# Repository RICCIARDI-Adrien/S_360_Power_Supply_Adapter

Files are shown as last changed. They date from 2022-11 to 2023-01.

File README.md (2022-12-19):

# S-360-xx power supply adapter

Add 4 10-A 2.5x5.5mm jack outputs and a 240V IEC connector with a switch to S-360-5 and S-360-12 AC/DC power supplies.

Finished casing side view
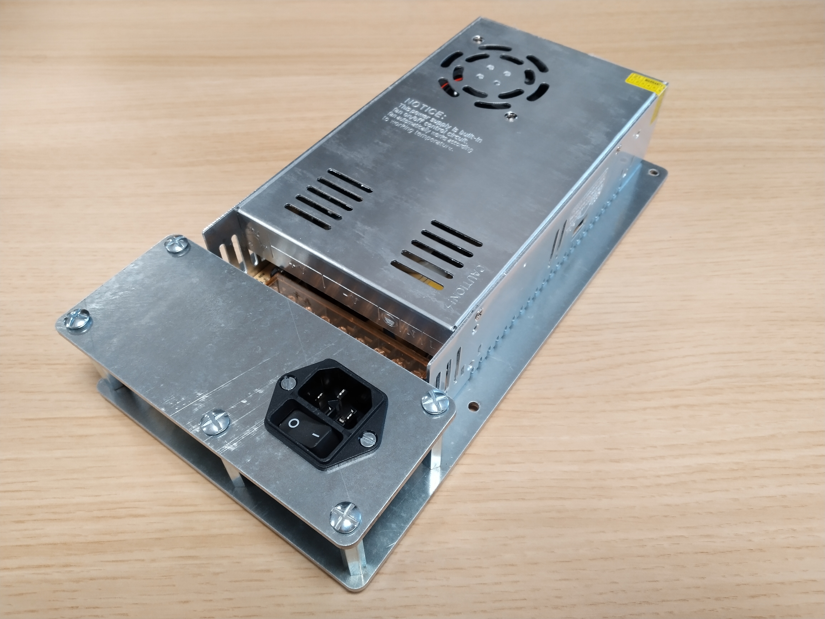
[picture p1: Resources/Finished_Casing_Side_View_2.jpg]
Finished casing side view


## Bill of materials

### Electronic parts

| Description | Reference | Amount |
| --- | --- | --- |
| IEC connector with integrated switch | DC11.0001.007 | 1 |
| 2.5X5.5mm power connector jack | PJ-082BH | 4 |

### Mechanical parts

| Description | Reference | Amount | Description |
| --- | --- | --- | --- |
| 40mm M4 steel hex standoff | 970400471 | 5 | Between upper plate and lower plate |
| 25mm M4 steel screw | - | 4 | Hold PCB |
| 10mm M4 steel screw | - | 14 | Fix upper plate to hex standoffs (5 screws), fix lower plate to hex standoffs (5 screws), fix power supply to lower plate (4 screws) |
| 16mm M3 steel screw | - | 4 | Fix IEC connector to upper plate |
| M4 steel nut | - | 12 | Hold PCB |
| M3 steel nut | - | 2 | Fix IEC connector to upper plate |
| 10mm M4 steel washer | - | 30 | Lock upper plate to hex standoffs (5 washers), lock lower plate to hex standoffs (5 washers), lock power supply to lower plate (4 washers), 4 per PCB screw (16 washers) |
| M3 steel washer | - | 2 | Lock IEC connector to upper plate |

## Documentation

The power supply drawing, found [here](https://fr.aliexpress.com/item/32713332357.html).
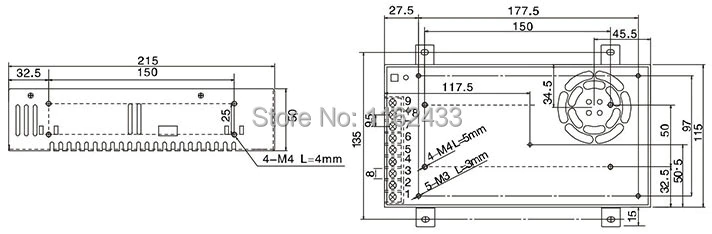
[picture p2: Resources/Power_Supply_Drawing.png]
Power supply drawing


## Photo gallery

### PCB

Naked PCB top
Naked PCB bottom

Assembled PCB top
Assembled PCB bottom

### Casing plates

Steel plates

### Assembly

Screwed PCB

Assembled power supply and PCB

Upper plate with soldered IEC cables

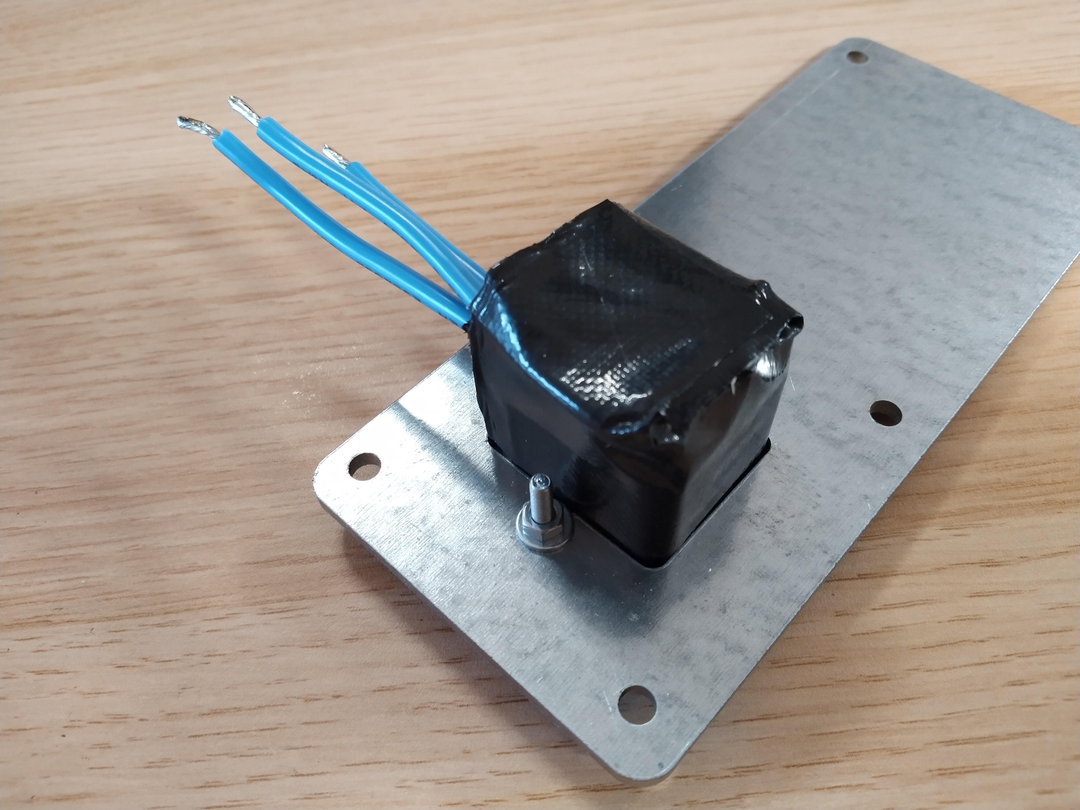
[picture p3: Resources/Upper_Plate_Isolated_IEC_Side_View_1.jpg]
Upper plate isolated IEC side view

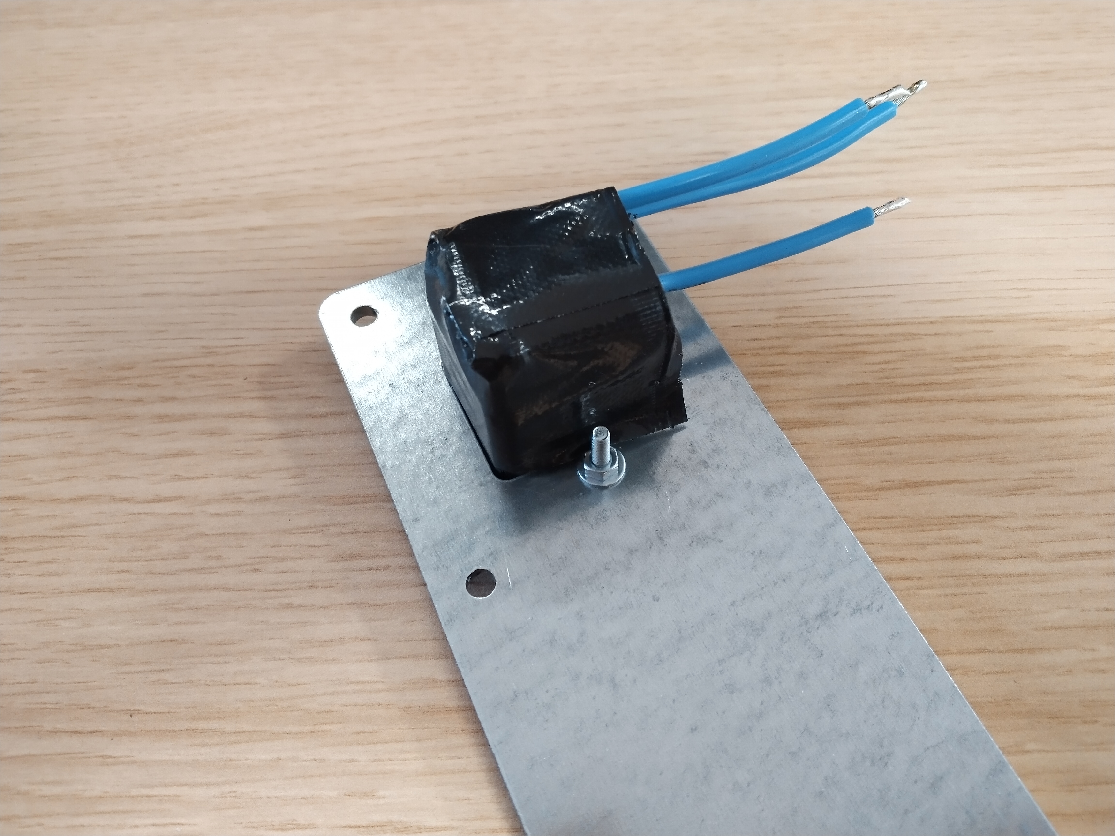
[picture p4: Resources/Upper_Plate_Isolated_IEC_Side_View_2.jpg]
Upper plate isolated IEC side view


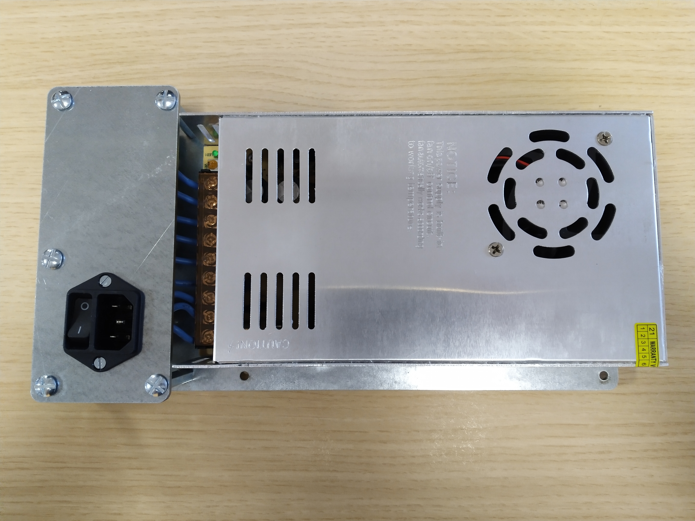
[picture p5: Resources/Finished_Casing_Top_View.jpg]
Finished casing top view


### Powering a test bench at BayLibre

BayLibre 1
BayLibre 2

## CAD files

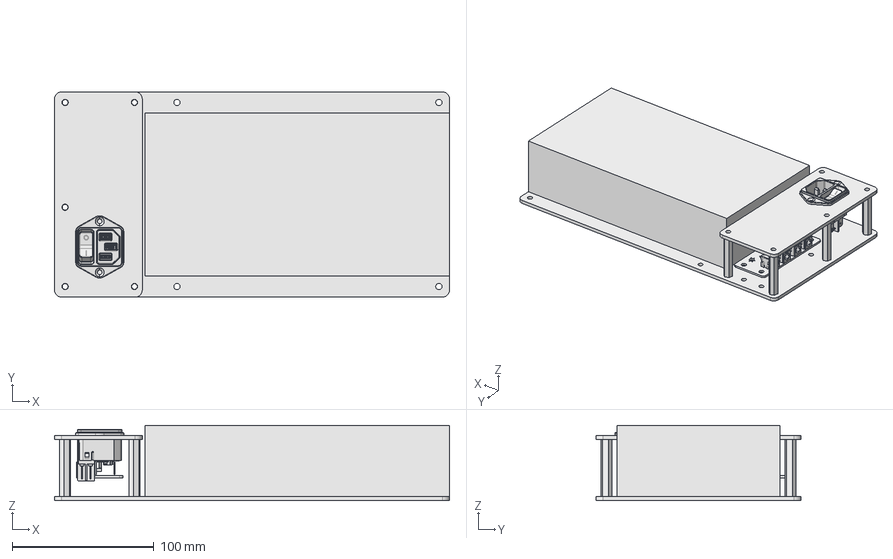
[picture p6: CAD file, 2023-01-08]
Casing/Casing.FCStd
279.0 x 145.0 x 53.0 mm
Power supply
S_360_Power_Supply_Adapter_PCB
Hex_Standoff_1 x 5
Lower plate
Upper plate

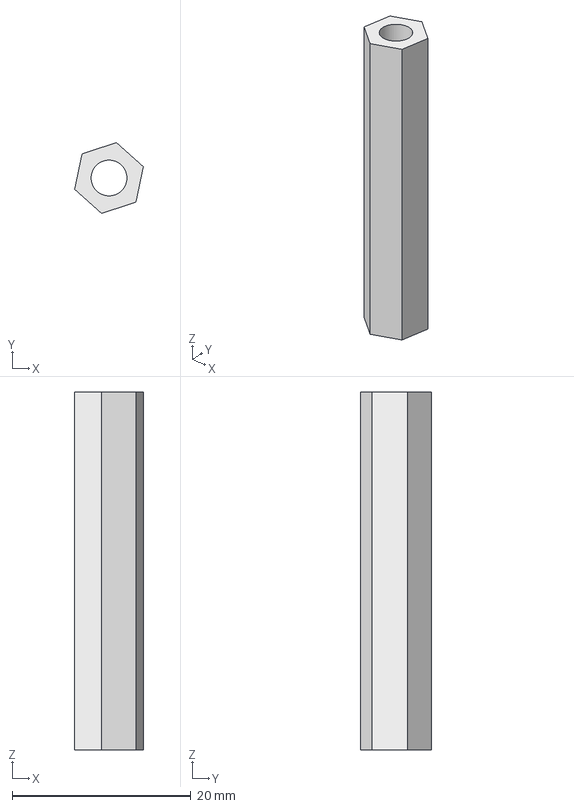
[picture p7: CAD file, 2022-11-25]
Casing/Hex_Standoff.step
7.68 x 7.91 x 40.0 mm

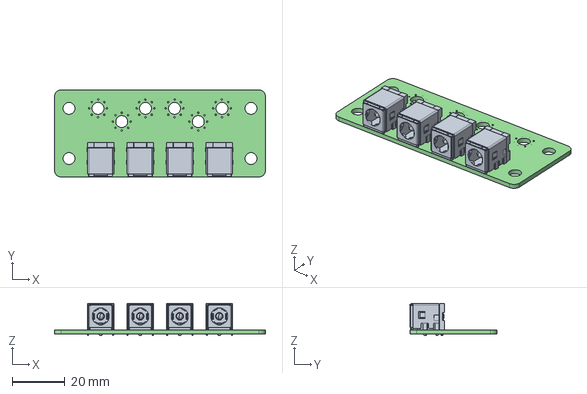
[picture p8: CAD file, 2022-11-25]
Casing/S_360_Power_Supply_Adapter_PCB.step
80.0 x 33.0 x 12.2 mm
S_360_Power_Supply_Adapter PCB

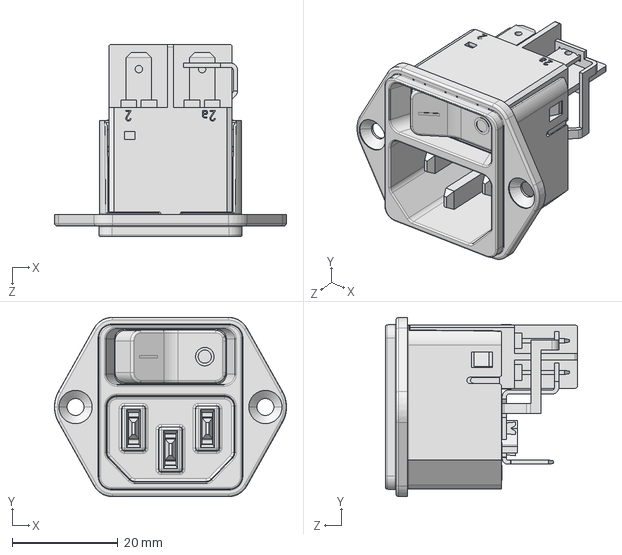
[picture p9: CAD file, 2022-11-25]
Casing/DC11_0001_007.step
44.0 x 34.0 x 36.5 mm

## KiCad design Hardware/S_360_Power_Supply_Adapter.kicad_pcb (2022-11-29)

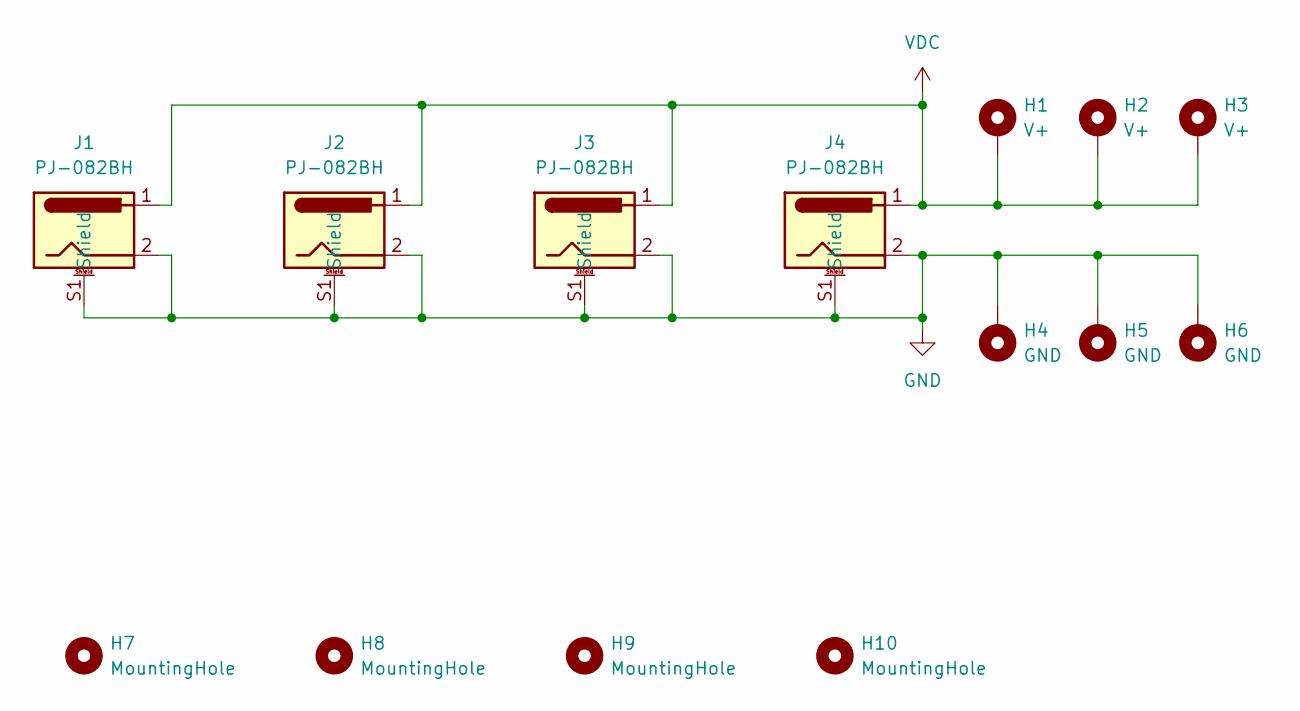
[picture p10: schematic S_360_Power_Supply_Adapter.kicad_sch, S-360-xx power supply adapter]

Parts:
H1, H2, H3: V+; MountingHole_4.5mm_Pad_Via
H4, H5, H6: GND; MountingHole_4.5mm_Pad_Via
H7, H8, H9, H10: MountingHole; MountingHole_4.5mm
J1, J2, J3, J4: PJ-082BH

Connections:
GND: H4.1, H5.1, H6.1, J1.2, J1.S1 (Shield), J1.S2 (Shield), J1.S3 (Shield), J1.S4 (Shield), J2.2, J2.S1 (Shield), J2.S2 (Shield), J2.S3 (Shield), J2.S4 (Shield), J3.2, J3.S1 (Shield), J3.S2 (Shield), J3.S3 (Shield), J3.S4 (Shield), J4.2, J4.S1 (Shield), J4.S2 (Shield), J4.S3 (Shield), J4.S4 (Shield)
VDC: H1.1, H2.1, H3.1, J1.1, J2.1, J3.1, J4.1

Board: 2 copper layers, 14 parts (0 on the bottom side), 2 nets, no tracks yet.

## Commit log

2022-11-24 Initial commit. Added README.md with the power supply drawing picture.
2022-11-24 Started casing modeling. Created the power supply block with its fastening holes.
    [Casing.FCStd]
2022-11-25 Added an empty KiCad project for the PCB.
    [S_360_Power_Supply_Adapter.kicad_pcb, S_360_Power_Supply_Adapter.kicad_sch]
2022-11-25 Added PJ-082BH barrel jack symbol, footprint and 3D model to PCB.
2022-11-25 Finished PCB schematic.
    [S_360_Power_Supply_Adapter.kicad_sch]
2022-11-25 Finished PCB routing.
    [S_360_Power_Supply_Adapter.kicad_pcb]
2022-11-25 Started casing lower plate design. Also imported the IEC connector and PCB 3D models to the casing.
    [Casing.FCStd, DC11_0001_007.step, S_360_Power_Supply_Adapter_PCB.step]
2022-11-25 Positioned the PCB on the casing lower plate.
    [Casing.FCStd]
2022-11-25 Added all casing lower plate fixation holes and all hex standoffs.
    [Casing.FCStd, Hex_Standoff.step]
2022-11-25 Started casing upper case. Removed the hex standoff in front of the power supply screw terminal to make screwing cables easier.
    [Casing.FCStd]
2022-11-25 Finished casing upper plate.
    [Casing.FCStd]
2022-11-25 Added a techdraw projection of the casing plates so they can easily be exported to DXF.
    [Casing.FCStd]
2022-11-28 Fixed the IEC connector fixation screw holes that could not be cut by a laser if the plate width was 3mm (there was too little margin between the hole and the connector cut).
    [Casing.FCStd]
2022-11-29 Added more clearance around PCB mounting holes so a nut or a washer can't scratch the mask and touch the copper, creating a short circuit.
    [S_360_Power_Supply_Adapter.kicad_pcb]
2022-12-13 Added electronic and mechanical bill of material to README.md.
2023-01-08 Made longer power supply fixation holes on the casing lower plate to accomodate with power supplies poor manufacturing tolerances.
    [Casing.FCStd]
